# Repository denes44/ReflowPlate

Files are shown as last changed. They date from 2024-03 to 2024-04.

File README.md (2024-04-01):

# Reflow Plate

This is just a little modification of the [original](https://github.com/Berkays/ReflowPlate/) design for myself.

I modified the plate to max out heating area and the 10x10 cm dimension.

I modified the controller PCB to be the same width as the plate, so you can mount the controller on top of the plate with spacers. Also the display and the rotary encoder is mounted directly to the PCB.

See at [Hardware](./Hardware/README.md).

## Original repo's description

### Summary

This project aims to make SMD soldering easier with a cost efficent solution by using a controller and a hot plate. Reflow Plate project was mainly inspired from the [DerSpatz](https://github.com/DerSpatz/PCB-reflow-solder-heat-plate) but ported to STM32 platorm and the firmware is entirely written from scratch to support modularity and ease of configuration. Firmware also incorporates some extra features by utilizing the extra memory and flash space provided by the more advanced stm32 chips. Project aims to be a complete solution by providing firmare, hardware, 3d models and even a PC control application.

### Hardware

Additional details on hardware can be found in [Hardware](./Hardware/README.md).

### Firmware

Additional details on firmware can be found in [Firmware](./Firmware/README.MD).

### 3D Enclosing Box

Additional details on 3d models can be found in [Firmware](./3D/README.md).

### GUI Application

Additional details on GUI application can be found in [GUI Readme](./GUI/README.md).

#### Sourcing

This project can be directly ordered by using JLCPCB assembly service. Connectors, 7A Fuse, Radial capacitors, LED are discarded from SMT assembly to reduce costs. OLED Display, Rotary Encoder, NTC, STLink (Used to flash) also have to be sourced seperately. For hot plate, I would recommend getting an aluminum plate as the costs are pretty much the same.

#### Discussion

Join the discord community for further discussion.



### Credits

- [DerSpatz](https://github.com/DerSpatz/PCB-reflow-solder-heat-plate) - For original hardware design

### License

Licenses linked to this main project can be found in the related sub-folders.

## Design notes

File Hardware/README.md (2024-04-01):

## About

This project contains required PCB design files. This board is mainly designed around the [original](https://github.com/Berkays/ReflowPlate/) design.

I modified the plate to max out heating area and the 10x10 cm dimension. The trace length (without the wider connection in the beginning) is 5023 mm, the calculated resistance is 1.787 Ohms. You can order this from JLCPCB in aluminium for a very cheap price.

I modified the controller PCB to be the same width as the plate, so you can mount the controller on top of the plate with spacers. Also the display and the rotary encoder is mounted directly to the PCB.

Everything in the schematics is (should be) the same as in the original project, except a few things:
- I needed to modify the voltage divider (R10, R11), because the original values are not available as basic parts at JLCPCB. It almost the same, even if you use the orginal firmware.
- I added two more capacitors (C17, C18) for the third side of the STM32
- I added a header with some GPIOs, because there was some spare space on the PCB for it.

Most of the parts are a basic part at JLCPCB (or preferred extended part, which does not have a load in fee), so it's pretty cheap to get this board assembled. Only F1, Q2 and Q3 needs to be soldered by hand (if you want to save on the load in fee on those two parts). And also the 5 THT capacitors (C12-15 and C10).

Controller PCB:

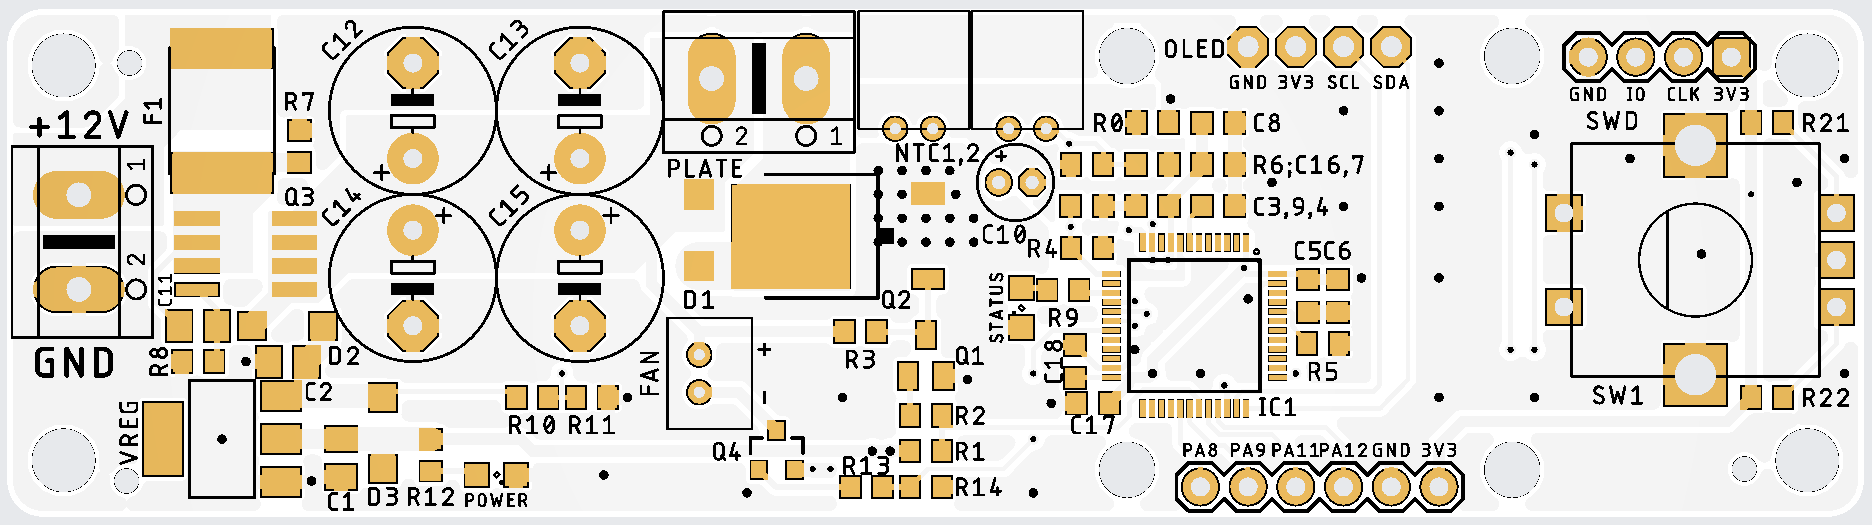
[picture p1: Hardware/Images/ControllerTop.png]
Controller PCB Top


Plate PCB:

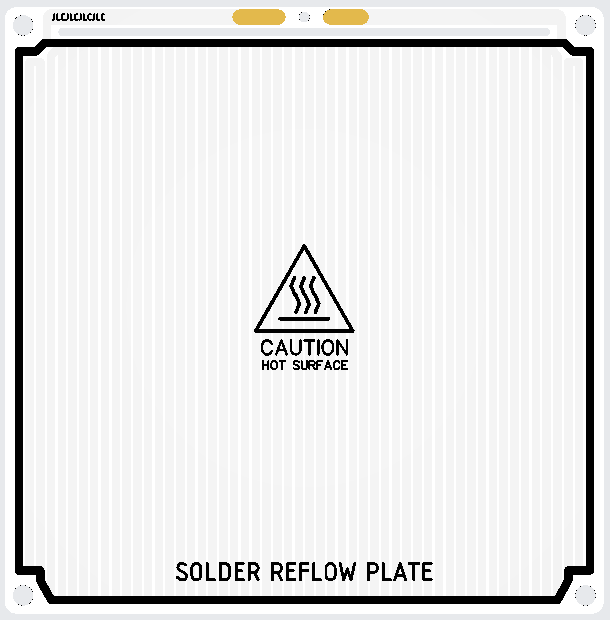
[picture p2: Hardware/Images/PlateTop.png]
Plate PCB Top


### Features

- Two NTC Support
- Rotary encoder input
- I2C Display
- Fan output

## License

This project is licensed under the MIT License - see the [LICENSE](LICENSE) file for details.

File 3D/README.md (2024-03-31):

## About 

This folder contains Google SketchUp and .STL files for a vent holder that is the same size as the plate and can hold a 60mm PC fan under the plate.

## Original project's content

### About

This project contains 3D models and design files used to create an enclosing box for the reflow plate system. It supports 4010 capacitor cooling fan, 128x64 0.96" OLED display, Rotary encoder module.

Public Onshape project can be accessed at [https://cad.onshape.com/documents/fabf8b8485aba982e8e00938/w/3c16bb25b752a8fd39e094e7/e/187e14039f52f81eb8a33bf7](https://cad.onshape.com/documents/fabf8b8485aba982e8e00938/w/3c16bb25b752a8fd39e094e7/e/187e14039f52f81eb8a33bf7)

### License

<br />This work is licensed under a <a rel="license" href="http://creativecommons.org/licenses/by/3.0/">Creative Commons Attribution 3.0 Unported License</a>.

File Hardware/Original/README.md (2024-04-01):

## About

This project contains required PCB design files. This board is mainly designed around the [DerSpatz V1.1 design](https://github.com/DerSpatz/PCB-reflow-solder-heat-plate) but ported to STM32 MCU platform. As the board is designed entirely in EasyEDA, you can easily order this board with parts assembled. Basic parts are used whenever possible to reduce the costs. I would recommend ordering the hot plate as an aluminum PCB as it has more or less the same cost.

Public EasyEda project can be found [here](https://oshwlab.com/berkaygursoy/reflowplate).

### Features

- Two NTC Support
- Rotary encoder input
- I2C Display
- Fan output

## License

This project is licensed under the MIT License - see the [LICENSE](LICENSE) file for details.

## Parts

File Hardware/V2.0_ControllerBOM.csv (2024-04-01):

Comment | Designator | Footprint | LCSC Part #
 | Q3 | SO-08
0R | R0 | R0603
1k | R2 R13 | R0603
2k | R7 | R0603
4.7k | R3 | R0603
4.7u | C6 C8 | C0603K
4.7u | C11 | C0805K
4.7u | C18 | C0603K
10k | R1 R4 R6 R8 R14 R21 R22 | R0603
10n | C9 | C0603K
10u | C2 | C0805K
16V 5A | F1 | SMD2920B
22u | C1 | C0805K
51R | R9 | R0603
100k | R5 | R0603
100n | C3 C4 C5 C7 C16 C17 | C0603K
120k | R11 | R0603
150R | R12 | R0603
470k | R10 | R0603
AMS1117-3.3 | VREG | SOT223
AO3400A | Q4 | SOT23-3
B5819W | D1 D2 D3 | SOD123
IRLR2905 | Q2 | TO252
KT-0805G | STATUS | SML0805
KT-0805Y | POWER | SML0805
SS8050 | Q1 | SOT23-BEC
STM32F030C8 | IC1 | P-LFQFP48-7X7

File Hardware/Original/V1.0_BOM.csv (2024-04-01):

ID | Name | Designator | Footprint | Quantity | Manufacturer Part | Manufacturer | Supplier | Supplier Part | Price
1 | 4.7uF | C11,C6,C8 | C0805 | 3 | CL21A475KAQNNNE | SAMSUNG(三星) | LCSC | C1779 | 0.011
2 | 2kΩ | R7 | R0805 | 1 | 0805W8F2001T5E | UNI-ROYAL(厚声) | LCSC | C17604 | 0.002
3 | 100nF | C16,C3,C4,C5,C7 | C0805 | 5 | CC0805KRX7R9BB104 | YAGEO(国巨) | LCSC | C49678 | 0.005
4 | NTC2 | H6 | HDR-F-2.54_1X2 | 1 |  |  | LCSC | C49661 | 0.035
5 | 10kΩ | R6,R14,R1,R4,R8 | R0805 | 5 | 0805W8F1002T5E | UNI-ROYAL(厚声) | LCSC | C17414 | 0.001
6 | 7A | 7A | FUSE-SMD_L6.1-W2.6 | 1 | S6125-F-5.0A | SART(萨特) | LCSC | C553942 | 0.115
7 | FAN | H5 | HDR-F-2.54_1X2 | 1 |  |  | LCSC | C49661 | 0.035
8 | AO3400A | Q4 | SOT-23-3_L2.9-W1.6-P1.90-LS2.8-BR | 1 | AO3400A | AOS | LCSC | C20917 | 0.074
9 | 150Ω | R13,R12 | R0805 | 2 | 0805W8F1500T5E | UNI-ROYAL(厚声) | LCSC | C17471 | 0.002
10 | 22uF | C1 | C0805 | 1 | CL21A226MAQNNNE | SAMSUNG(三星) | LCSC | C45783 | 0.026
11 | 10uF | C2 | C0805 | 1 | CL21A106KAYNNNE | SAMSUNG(三星) | LCSC | C15850 | 0.013
12 | 10nF | C9 | C0805 | 1 | CL21B103KBANNNC | SAMSUNG(三星) | LCSC | C1710 | 0.009
13 | 1u | C10 | CAP-D3.0×F1.5 | 1
14 | B5819W | D1,D2,D3 | SOD-123_L2.7-W1.6-LS3.7-RD-1 | 3 | B5819W SL | CJ(江苏长电/长晶) | LCSC | C8598 | 0.03
15 | SS8050 | Q1 | SOT-23-3_L2.9-W1.3-P1.90-LS2.4-BR | 1 | SS8050 | CJ(江苏长电/长晶) | LCSC | C2150 | 0.015
16 | IRLR8726TRPBF | Q2 | TO-252-2_L6.6-W6.1-P4.58-LS9.9-TL | 1 | IRLR8726TRPBF | Infineon(英飞凌) | LCSC | C81137 | 0.18
17 | WSP4409A | Q3 | SOP-8_L4.9-W3.9-P1.27-LS6.0-BL | 1 | WSP4409A | WINSOK微硕 | LCSC | C2880527 | 0.458
18 | 1kΩ | R2 | R0805 | 1 | 0805W8F1001T5E | UNI-ROYAL(厚声) | LCSC | C17513 | 0.002
19 | 4.7kΩ | R3 | R0805 | 1 | 0805W8F4701T5E | UNI-ROYAL(厚声) | LCSC | C17673 | 0.002
20 | 100kΩ | R5,R11 | R0805 | 2 | 0805W8F1003T5E | UNI-ROYAL(厚声) | LCSC | C149504 | 0.002
21 | 390kΩ | R10 | R0805 | 1 | 0805W8F3903T5E | UNI-ROYAL(厚声) | LCSC | C17656 | 0.002
22 | AMS1117-3.3 | U4 | SOT-223-3_L6.5-W3.4-P2.30-LS7.0-BR | 1 | AMS1117-3.3 | AMS | LCSC | C6186 | 0.144
23 | STM32F030C8T6 | U1 | LQFP-48_L7.0-W7.0-P0.50-LS9.0-BL | 1 | STM32F030C8T6 | ST | LCSC | C23922 | 0.912
24 | Encoder | H1 | HDR-F-2.54_1X5 | 1 |  |  | LCSC | C50950 | 0.06
25 | DISPLAY | H2 | HDR-F-2.54_1X4 | 1 |  |  | LCSC | C225501 | 0.076
26 | NTC | H3 | HDR-F-2.54_1X2 | 1 |  |  | LCSC | C49661 | 0.035
27 | SWD | H4 | HDR-F-2.54_1X4 | 1 |  |  | LCSC | C225501 | 0.076
28 | 680uF | C12,C13,C14,C15 | CAP-D10.0×F5.0 | 4
29 | 5.0-02P | U2 | CONN-TH_DG125-5.0-02P-14-00A | 1 | DG125-5.0-02P-14-00A(H) | DEGSON(高正) | LCSC | C784572 | 0.32
30 | PWR | LED1 | LED-TH_BD3.0_RED | 1 | 204-10SDRD/S530-A3-L | EVERLIGHT(台湾亿光) | LCSC | C84774 | 0.035
31 | 5.0-2P | U5 | CONN-TH_DG125-5.0-02P-14-00A | 1 | DG125-5.0-02P-14-00A(H) | DEGSON(高正) | LCSC | C784572 | 0.32
32 | SHORTING_LINK | LK3 | SHORTING_LINK_DIFF_NAMED_NETS | 1

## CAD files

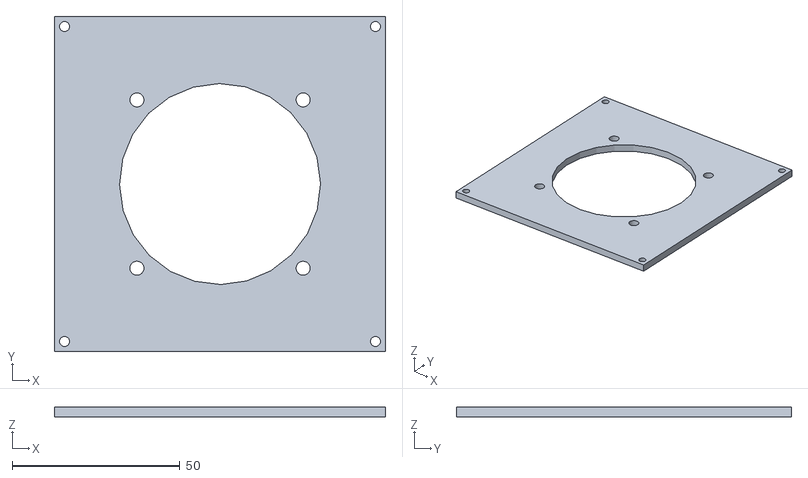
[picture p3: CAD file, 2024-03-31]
3D/VentHolder_60.stl
98.8 x 100.0 x 3.00

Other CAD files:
3D/VentHolder_60.skp

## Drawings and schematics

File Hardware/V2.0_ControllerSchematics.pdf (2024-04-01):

C11 | SW¹ | SW¹

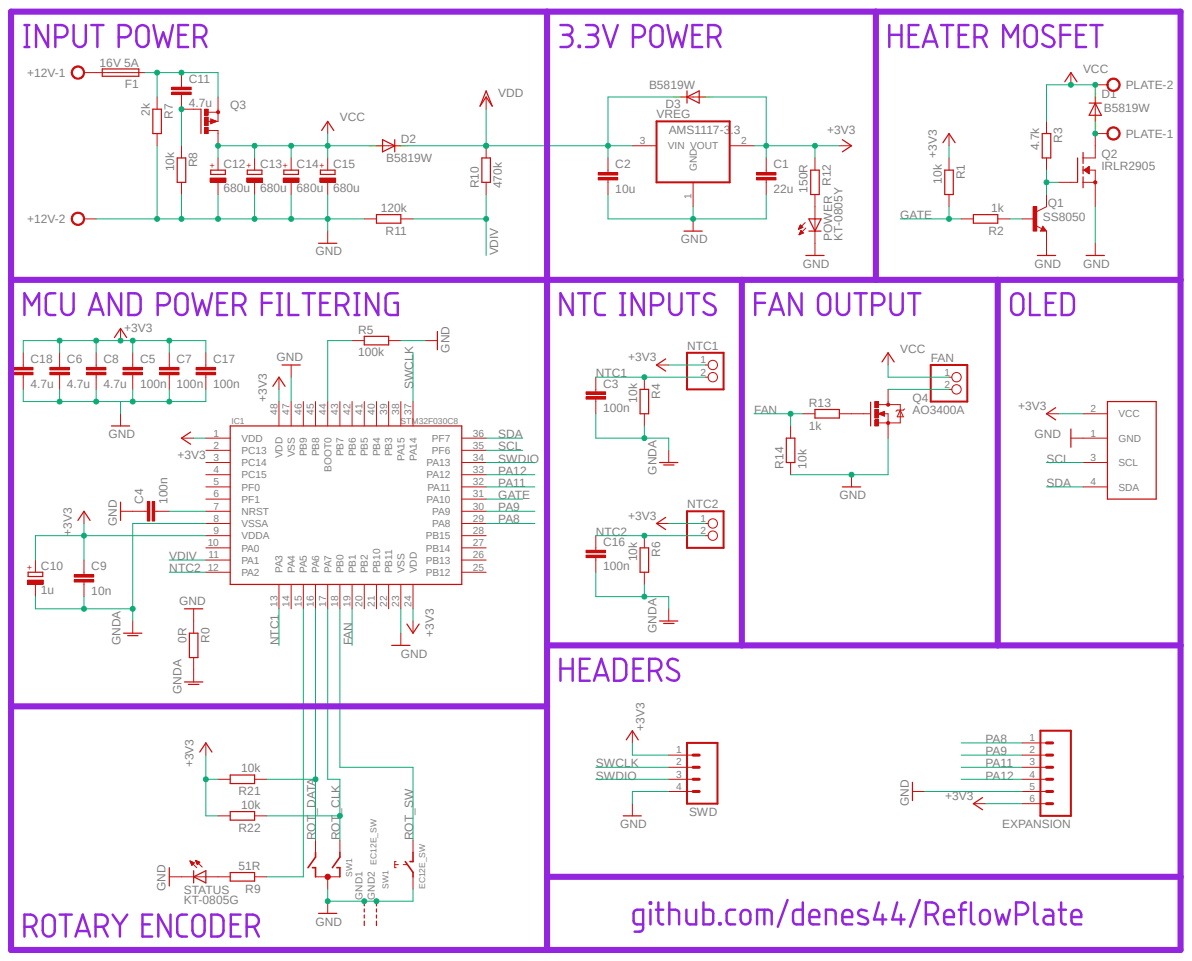
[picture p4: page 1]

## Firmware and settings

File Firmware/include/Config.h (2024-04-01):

#include "Base.h"

#include "Features/config_temperature.h"

//===========================================================================
//============================= System Configs ==============================
//===========================================================================
#define TASKER_MAX_TASKS 15
#define BUTTON_MAX_COUNT 1
#define ADC_RESOLUTION 12
#define ADC_MAX ((2 << (ADC_RESOLUTION - 1)) - 1)
#define ADC_CORRECTION 1.0475
#define OPERATING_VOLTAGE 3.3                     // V
#define VDIV_R1 470.0                             // Ω
#define VDIV_R2 120.0                             // Ω
#define INPUT_VOLTAGE 12.0                        // V
#define MIN_ALLOWED_VOLTAGE (INPUT_VOLTAGE - 1.0) // V
#define MAX_ALLOWED_VOLTAGE (INPUT_VOLTAGE + 1.0) // V

#define INVERT_SCREEN DISABLED

#define REFLOW_DURATION 300  // s. Profile is divided into RESOLUTION sized sections.
#define REFLOW_RESOLUTION 15 // s.
#define REFLOW_POINT_COUNT (REFLOW_DURATION / REFLOW_RESOLUTION)
#define AUTOMATIC_MODE_HISTORY_RESOLUTION 4

#define TEMP_UPDATE_INTERVAL 250  // ms
#define HEAT_UPDATE_INTERVAL 1000 // ms

#define INVERT_ENCODER DISABLED
#define ENCODER_THRESHOLD 50                 // ±
#define THERMAL_RUNAWAY_THRESHOLD 4          // °C
#define THERMAL_RUNAWAY_TIMESPAN (20 * 1000) // ms
#define MAX_SAFE_TEMP 70                     // °C

//===========================================================================
//============================= Features ====================================
//===========================================================================
#define SERIAL_COMM ENABLED
#define WAIT_SAFE_TEMP ENABLED
#define FAN_COOLDOWN DISABLED
#define PREHEAT ENABLED

#define TEMPERATURE_METHOD NTC_CURVE

//===========================================================================
//============================= Heater Settings =============================
//===========================================================================
#define HEATING_ELEMENT_NOMINAL_RESISTANCE 1.787       // Ω
#define HEATING_ELEMENT_RESISTANCE_PER_DEGREE 0.0085 // °C/Ω
#define MAX_CURRENT 5.5                              // A
#define MIN_CURRENT 1.0                              // A
#define MAX_TEMP 160                                 // °C
#define MIN_TEMP 30                                  // °C
#define KI 0.1
#define KP 8
#define KD 0

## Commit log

2024-03-31 Add new vent holder 3D file.
    [VentHolder_60.skp, VentHolder_60.stl]
2024-04-01 Modify Hardware
    [V1.0_BOM.csv, V1.0_PNP.csv, V2.0_ControllerBOM.csv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]
